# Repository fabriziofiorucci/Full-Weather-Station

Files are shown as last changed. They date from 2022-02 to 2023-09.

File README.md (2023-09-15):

# Full weather station

## Description

This is a MQTT-enabled, weather station powered by a Wemos D1 minicontroller and built with 3D-printed parts. It supports OTA updates.
The weather station is meant to be pole-mounted.

Used sensors and parts are:

- Wemos D1 minicontroller
- Wind speed: Anemometer with analog voltage output (like https://www.adafruit.com/product/1733)
- Visible light: BH1750FVI Light intensity (lux) sensor
- UV light: VEML6070 uv sensor
- Air quality/pollution: Digital Particle Concentration Laser Sensor PMS5003
- Rain quantity: Tipping bucket rain gauge (like https://www.bc-robotics.com/shop/tipping-rain-gauge/)
- Rain level: Capacitive soil moisture sensor
- Temperature and humidity: SHT21
- Pressure: BME280
- Wind speed decoding: ADS1115 16-Bit ADC - 4 Channel with Programmable Gain Amplifier
- LM7805 linear voltage regulator
- 1x 1.8kohm resistor
- 1x 1kohm resistor
- 2, 3, 4 & 5 pins JST XH connectors
- 3 poles PCB screw terminal blocks
- 12-15V 2A power supply
- M3 and M4 Torx screws and bolts
- Cable glands
- 2.54mm / 1 inch PVC pipe

This project is on Thingiverse at https://www.thingiverse.com/thing:5027011

## Schematics

The circuit can be quickly built on a single layer perfboard. It can be powered by a 12V 2A power supply. The onboard LM7805 generates the 5V voltage required for most components. The BME280 sensor is powered at 3.3v directly from the Wemos D1.



## Wemos D1 sketch 

The Wemos sketch can be uploaded using Arduino IDE. The software periodically polls sensors and publishes all readings through MQTT. To reduce wear and extend service life, PMS5003 laser is switched off when not reading.
Over-The-Air updates are supported with no need to physically access the Wemos unit.

The sketch must be configured to point to your MQTT broker and to connect to your WiFi network (see "CUSTOMIZE HERE" sessions)

It relies on https://github.com/SwapBap/PMS for PMS5003 communication

## 3D components

All parts should be printed using:

- weatherproof filament (ASA or PETG)
- 3 walls
- 0.1mm layer height
- print plate adhesion raft in case it's needed

The Stevenson shield is https://www.thingiverse.com/thing:1053967 printed at 65% of the original size:

- Stevenson_screen_Side_Ring.STL (print 5 times)
- Stevenson_screen_Top_Slant_Roof.STL (print once)
- Stevenson_screen_Base.STL (print once)
- 100mmX190mm_Internal_Bracket_for_6_Side_Rings.STL (print once)

The Anemometer 1/4-20 adapter is Anemometer_Adapter_riser_version.stl, from https://www.thingiverse.com/thing:2710360

## Complete build

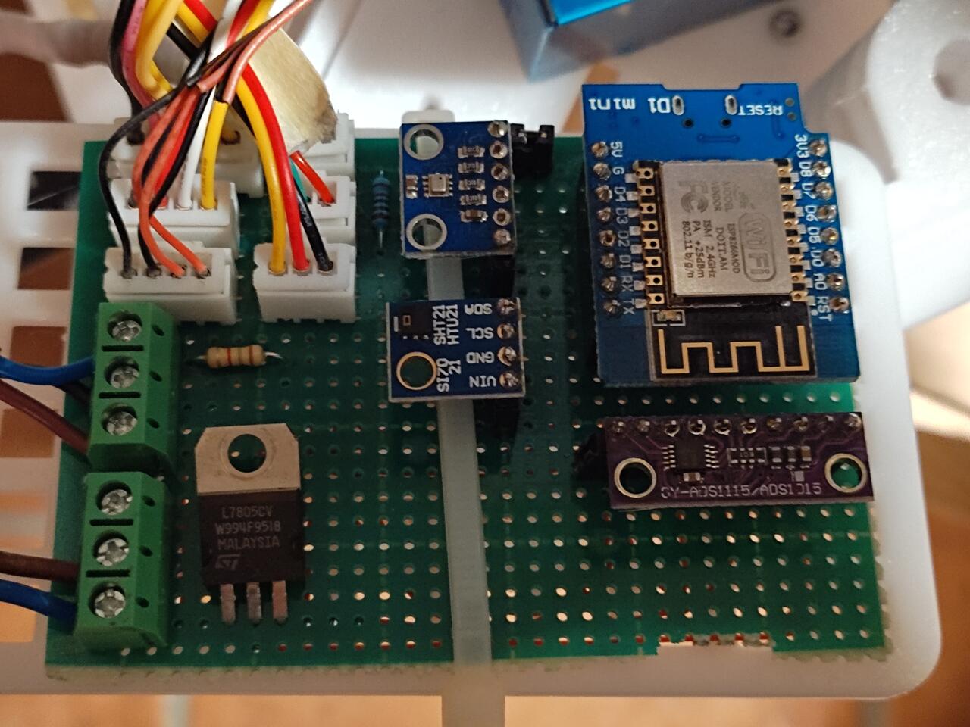
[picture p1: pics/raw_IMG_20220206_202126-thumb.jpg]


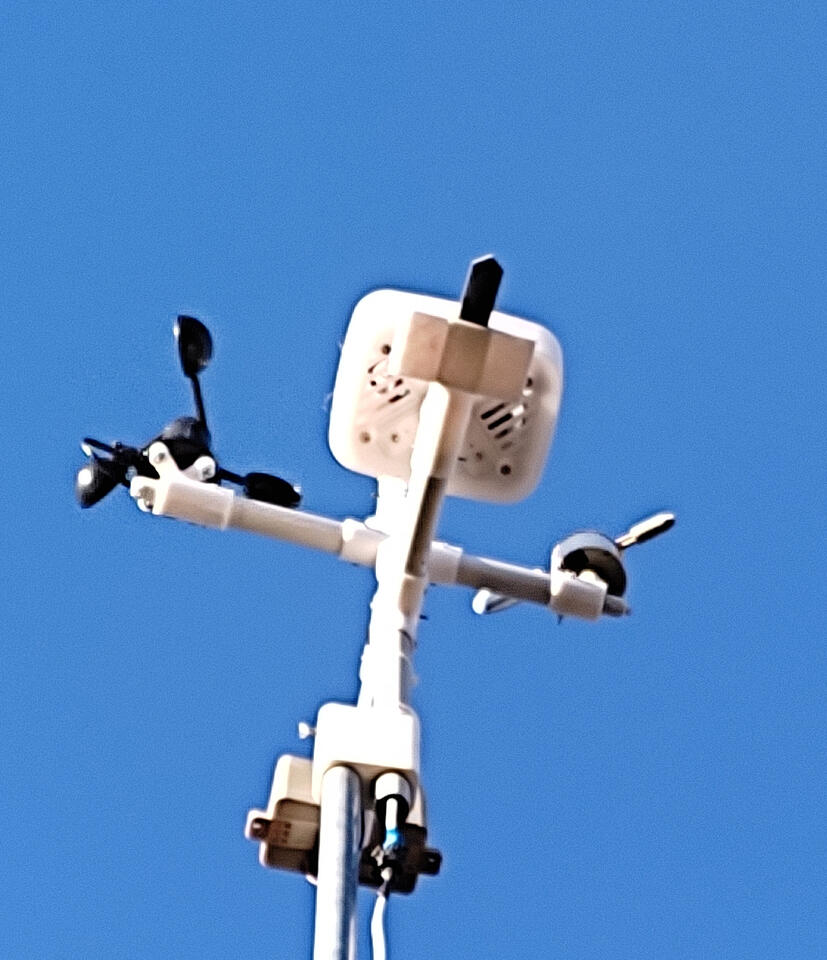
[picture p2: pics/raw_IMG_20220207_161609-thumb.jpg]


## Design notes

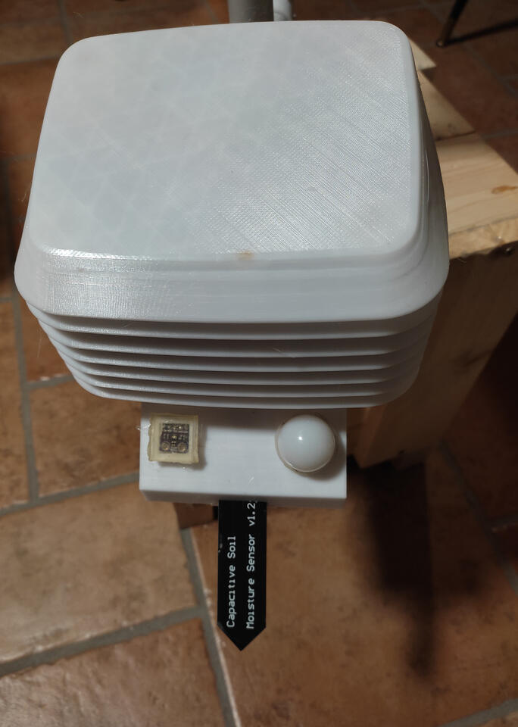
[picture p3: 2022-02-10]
pics/raw_IMG_20220206_173706-thumb.jpg

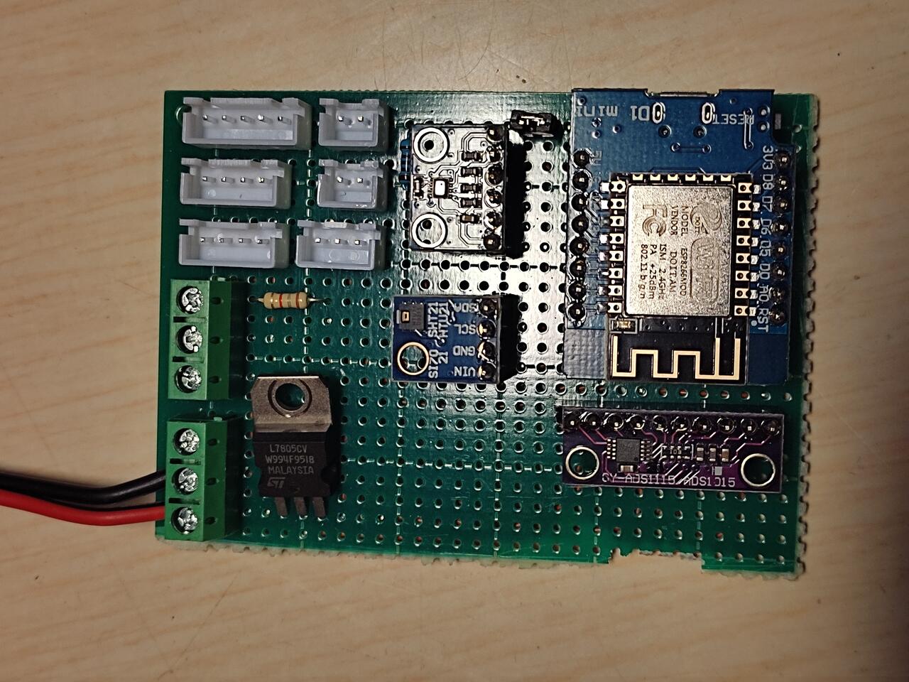
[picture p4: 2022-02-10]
pics/raw_IMG_20220206_202206-thumb.jpg

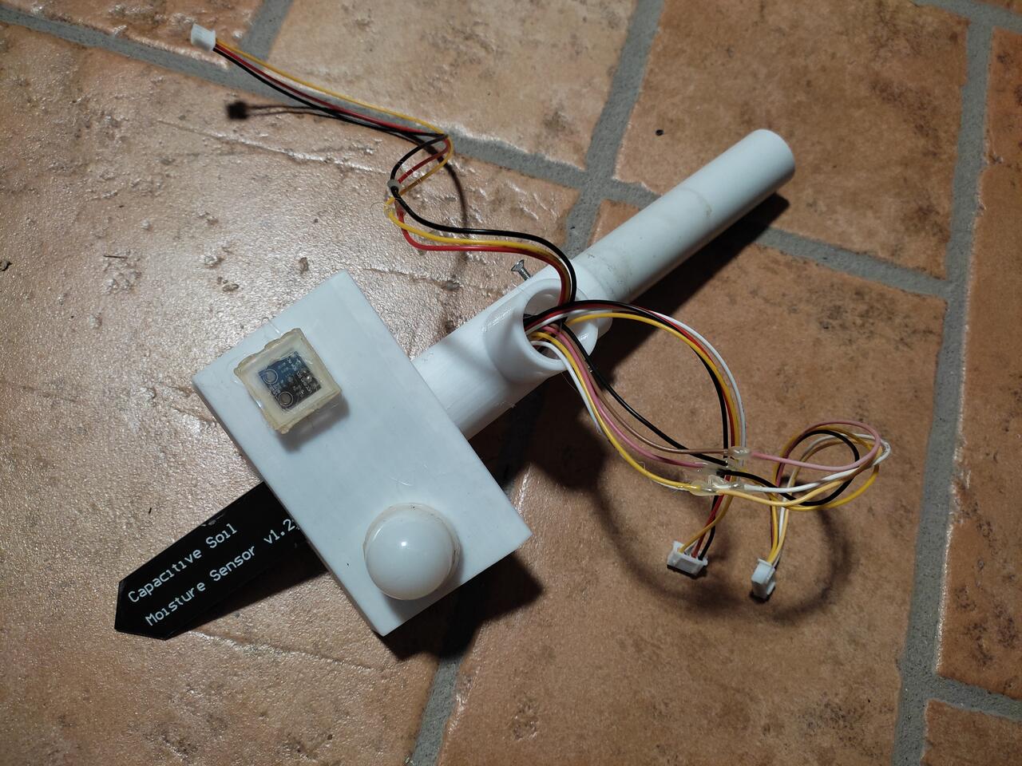
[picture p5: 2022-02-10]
pics/raw_IMG_20220206_144430-thumb.jpg

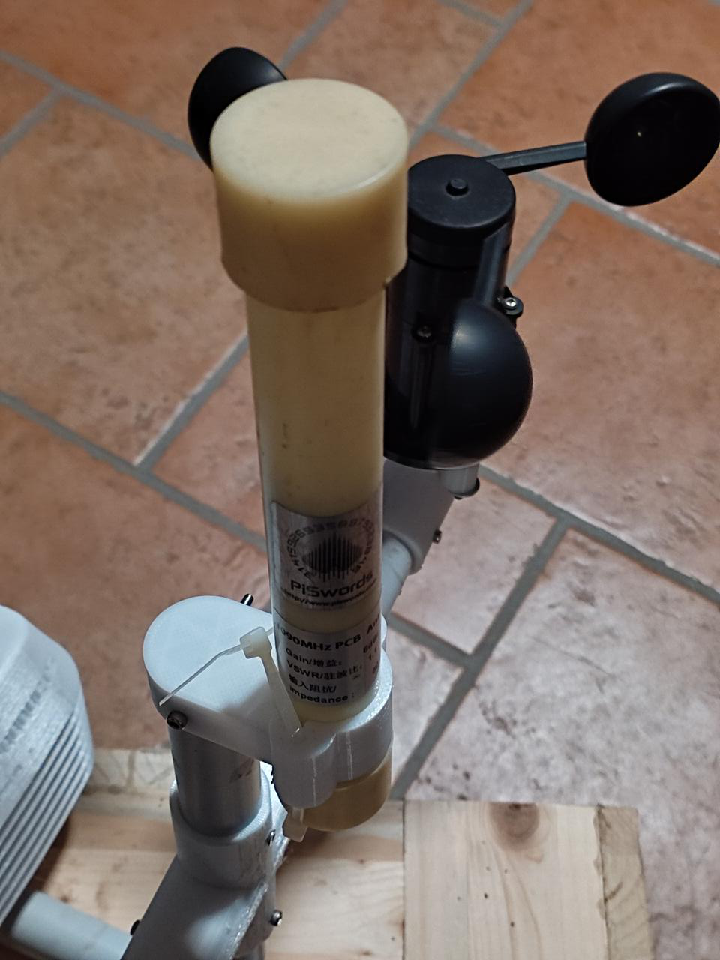
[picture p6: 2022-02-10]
pics/raw_IMG_20220206_173800-thumb.jpg

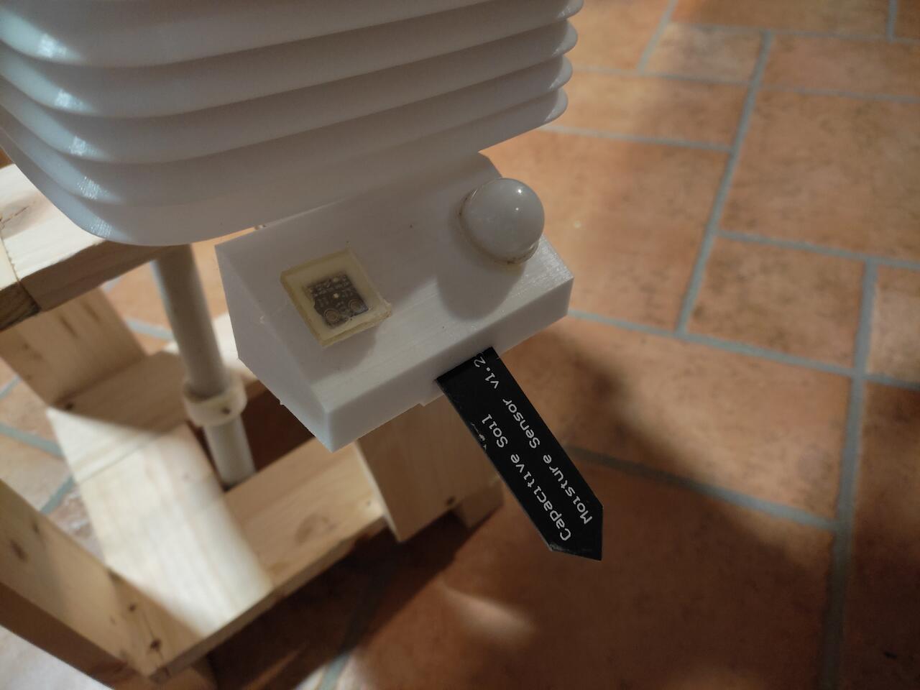
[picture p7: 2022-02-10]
pics/raw_IMG_20220206_173653-thumb.jpg

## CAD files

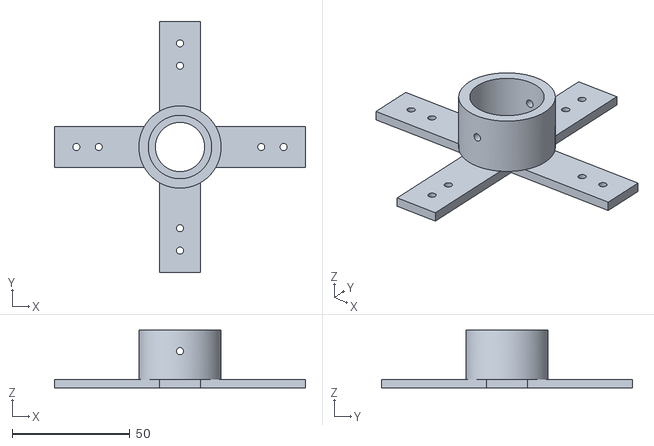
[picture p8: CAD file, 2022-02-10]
CAD/Stevenson base holder 65% scale v4.stl
106.6 x 106.6 x 24.5

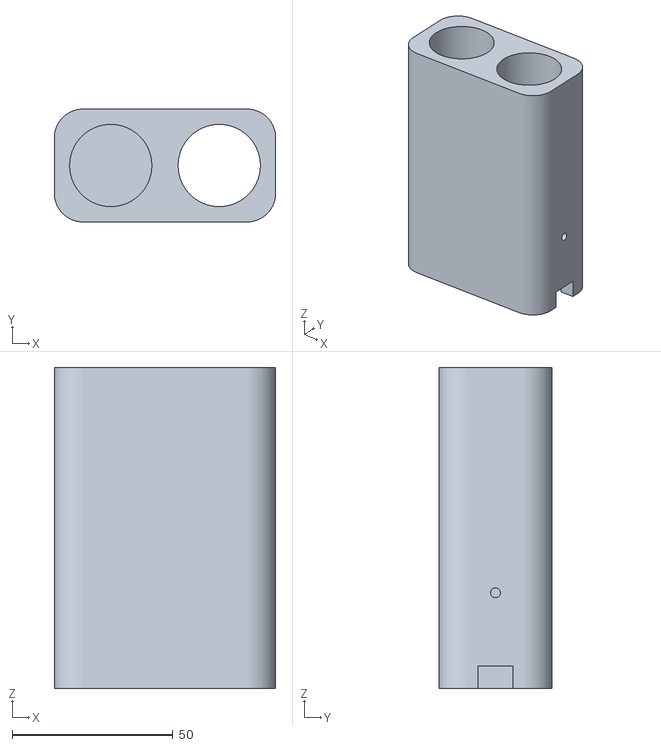
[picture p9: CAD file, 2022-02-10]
CAD/pole clamp.stl
69.0 x 35.2 x 100.0

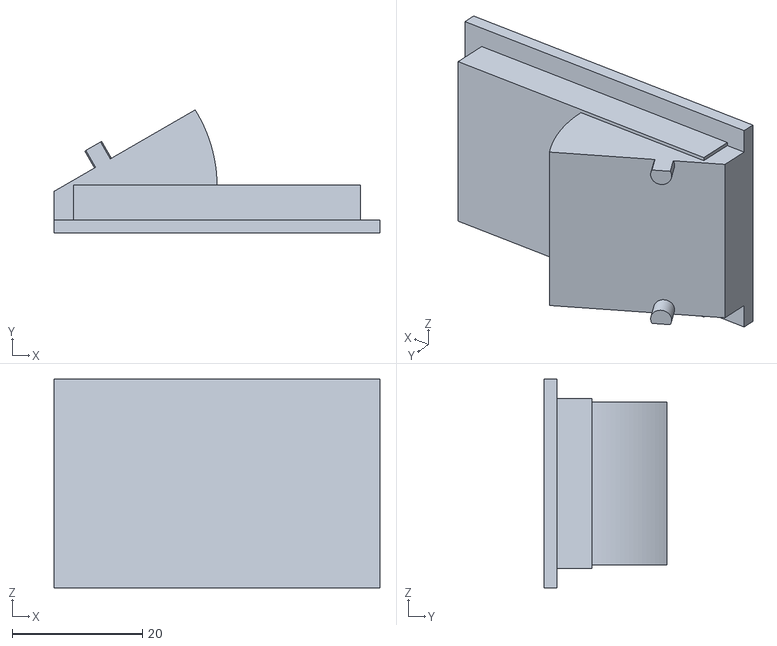
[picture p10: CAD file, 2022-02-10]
CAD/Stevenson to 1 inch pipe L joint v1 - lid.stl
50.0 x 18.9 x 32.0

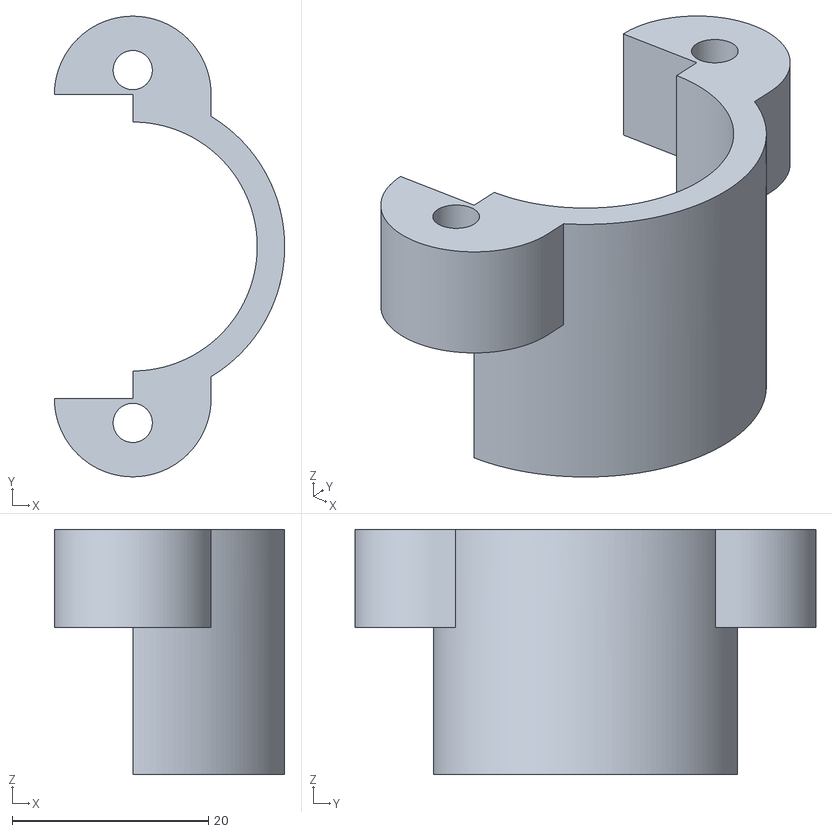
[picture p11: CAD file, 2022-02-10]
CAD/ADS-B latch.stl
23.5 x 47.0 x 25.0

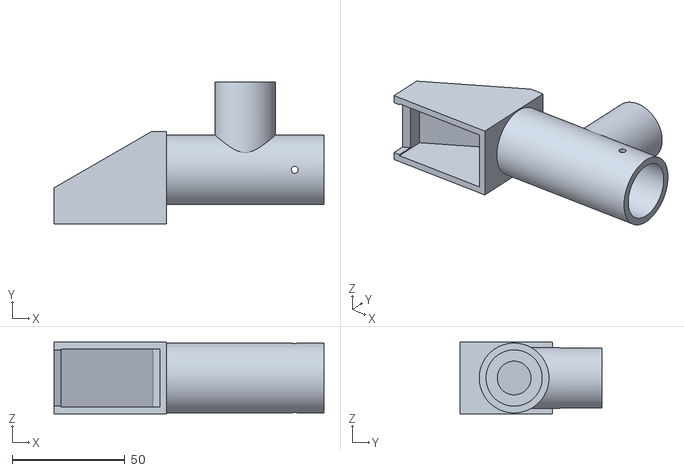
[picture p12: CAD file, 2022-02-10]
CAD/Stevenson to 1 inch pipe L joint v1.stl
120.0 x 63.0 x 32.0

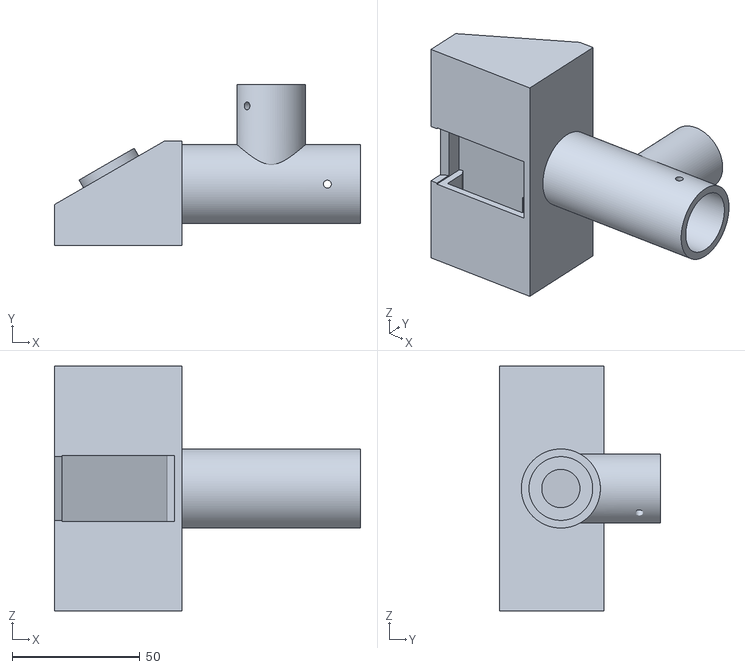
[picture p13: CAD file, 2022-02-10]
CAD/moisture sensor + stevenson to 1 inch pipe.stl
120.0 x 63.0 x 96.0

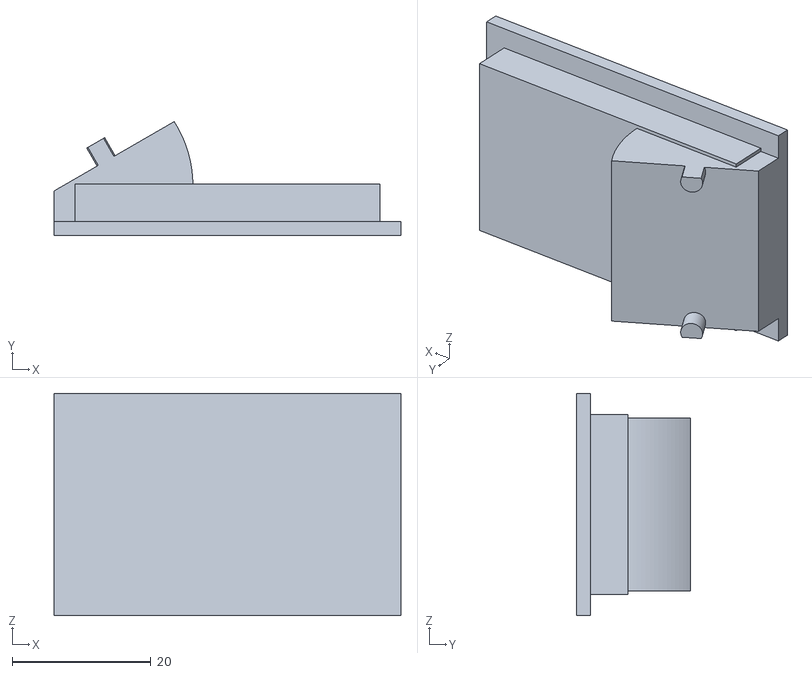
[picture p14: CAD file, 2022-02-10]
CAD/moisture sensor + stevenson to 1 inch pipe - lower lid.stl
50.0 x 16.4 x 32.0

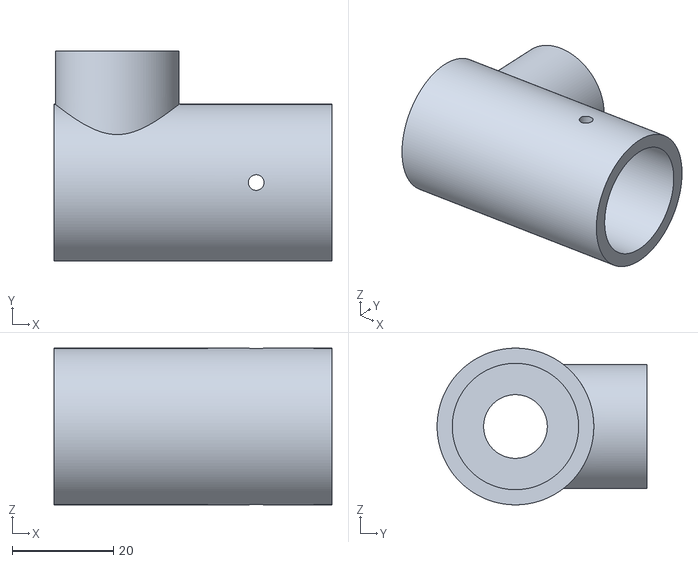
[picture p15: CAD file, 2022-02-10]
CAD/anemometer to 1 inch pipe L joint.stl
55.0 x 41.5 x 31.0

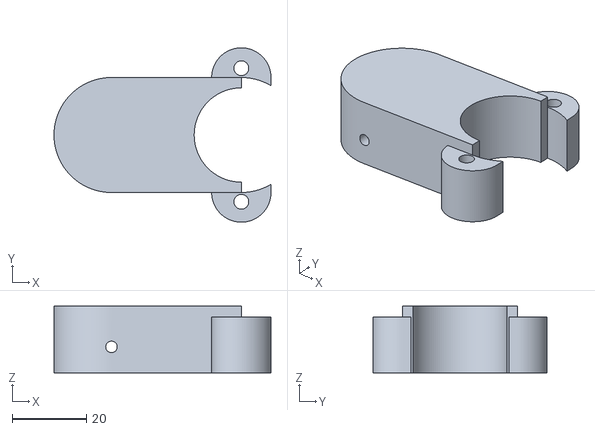
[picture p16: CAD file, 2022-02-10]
CAD/ADS-B to pole.stl
58.5 x 47.0 x 18.0

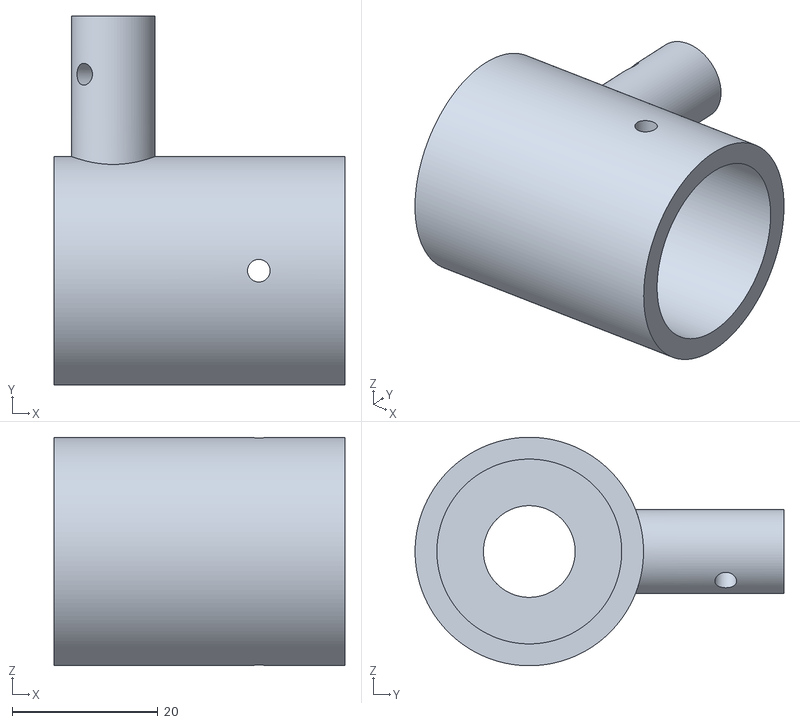
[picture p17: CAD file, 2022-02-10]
CAD/wind vane 1 inch pipe L joint v3.stl
40.0 x 50.7 x 31.4

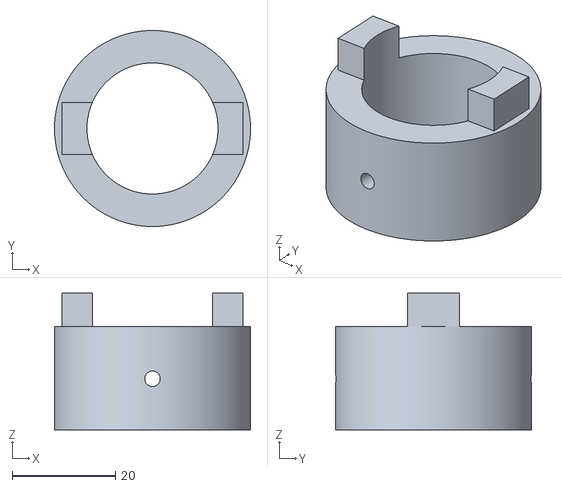
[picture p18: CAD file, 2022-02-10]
CAD/pole holder.stl
38.0 x 38.0 x 26.5

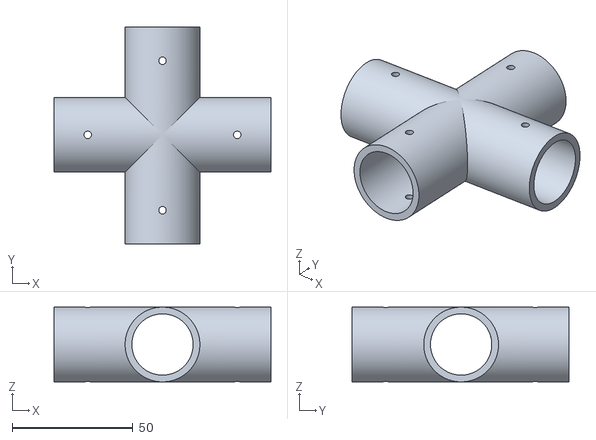
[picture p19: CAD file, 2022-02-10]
CAD/1 inch pipe X joint.stl
90.0 x 90.0 x 31.0

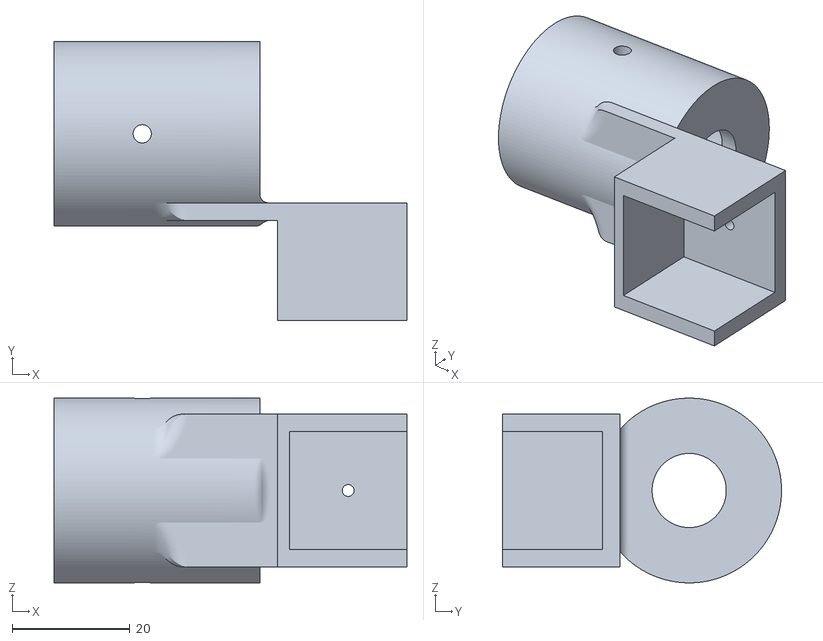
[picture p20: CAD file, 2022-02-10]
CAD/tipping bucket 1 inch pipe joint.stl
60.0 x 47.4 x 31.4

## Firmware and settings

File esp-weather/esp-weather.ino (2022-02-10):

/*
 * Full weather station
 *
 * Wemos D1:
 *
 * A0 -> capacitive soil moisture sensor v1.2
 * D2 -> I2C SDA
 * D1 -> I2C SCL
 * D3 = Rain tipping bucket (tipping bucket wires connected to D3 and GND, D3 set as INPUT_PULLUP)
 * D6 -> to PMS5003 RX (pin 4)
 * D7 -> to PMS5003 TX (pin 5)
 *
 * PMS5003:
 * Pin 1 -> +5vcc
 * Pin 2 -> GND 
 * Pin 3 -> Set @3.3v (low=sleep) - not connected
 * Pin 4 -> RX -> to Wemos D7
 * Pin 5 -> TX -> to Wemos D6
 * Pin 6 -> Reset @3.3v (low=reset) - not connected
 * Pin 7 -> NC
 * Pin 8 -> NC
 *
 * I2C:
 * - BH1750FVI (I2C 0x23 - addr pin to GND)
 * - VEML6070 (I2C 0x38/low address + 0x39/high address)
 * - SHT21 (I2C 0x40)
 * - BMP280 (I2C 0x76)
 * - ADS1115 (I2C 0x48)
 * 
 * ADS1115 gain: 2x, input range=+/-2.048v
 * ADS1115 addr pin = GND (0x48)
 * A0 - +5V reference
 * A1 - Free
 * A2 - Wind vane
 * A3 - Anemometer range 0.4-2v, vcc>=9v connected to ADC through R=1.8k, max current A0=5mA - 0.4V (0 m/s wind) up to 2.0V (for 32.4m/s wind speed)
 *
 * Adafruit Anemometer wires:
 * Brown: power
 * Black: ground
 * Blue : signal
 *
 * Libraries used:
 * 
 * https://github.com/RobTillaart/SHT2x
 * https://github.com/adafruit/Adafruit_ADS1X15
 * https://github.com/adafruit/Adafruit_VEML6070
 * https://github.com/adafruit/Adafruit_BMP280_Library
 * https://github.com/claws/BH1750
 * https://github.com/jandrassy/ArduinoOTA
 * https://github.com/SwapBap/PMS
*/

#include <Wire.h>
#include <ESP8266WiFi.h>
#include <PubSubClient.h>
#include <NTPClient.h>
#include <WiFiUdp.h>
#include <SoftwareSerial.h>
#include "PMS.h"
#include "Adafruit_VEML6070.h"
#include <BH1750.h>
#include <Adafruit_Sensor.h>
#include <Adafruit_BMP280.h>
#include <Adafruit_ADS1X15.h>
#include <ArduinoOTA.h>
#include "SHT2x.h"


// --------------- CUSTOMIZE HERE WIFI PARAMETERS
const char* ssid = "MySSID";
const char* password = "MyWifiPassword";

IPAddress ip(192, 168, 1, 35);
IPAddress gateway(192, 168, 1, 5);
IPAddress subnet(255, 255, 255, 0);


// --------------- CUSTOMIZE HERE MQTT PARAMETERS
const char* mqttServer = "mqtt-server-ip";
const int mqttServerPort = 1883;
const char* mqttClientUsername="esp-weather";
const char* mqttClientPassword="mymqttpassword";

const char* topicRain="esp-weather/rain/percentage";
const char* topicRainTipping="esp-weather/rain/tipping";
const char* topicLightUVraw="esp-weather/light/uv/raw";
const char* topicLightUVlevel="esp-weather/light/uv/level";
const char* topicLightLux="esp-weather/light/lux";
const char* topicBMEtemperature="esp-weather/sht21/temperature";
const char* topicBMEpressure="esp-weather/bme280/pressure";
const char* topicBMEhumidity="esp-weather/sht21/humidity";
const char* topicWindSpeed="esp-weather/wind/speed";
const char* topicWindVane="esp-weather/wind/direction";
const char* debugTopic="esp-weather/debug";
const char* topicADC_a0="esp-weather/ads1115/a0";
const char* topicADC_a1="esp-weather/ads1115/a1";
const char* topicADC_a2="esp-weather/ads1115/a2";
const char* topicADC_a3="esp-weather/ads1115/a3";
const char* controlTopic="esp-weather/control";

// Particulate matter sensor
#define   PMS_STATE_ASLEEP        0   // Low power mode, laser and fan off
#define   PMS_STATE_WAKING_UP     1   // Laser and fan on, not ready yet
#define   PMS_STATE_READY         2   // Warmed up, ready to give data
uint8_t   g_pms_state           = PMS_STATE_WAKING_UP;
uint32_t  g_pms_state_start     = 0;  // Timestamp when PMS state last changed
uint8_t   g_pms_ae_readings_taken  = false;  // true/false: whether any readings have been taken
uint8_t   g_pms_ppd_readings_taken = false;  // true/false: whether PPD readings have been taken

uint16_t  g_pm1p0_sp_value      = 0;  // Standard Particle calibration pm1.0 reading
uint16_t  g_pm2p5_sp_value      = 0;  // Standard Particle calibration pm2.5 reading
uint16_t  g_pm10p0_sp_value     = 0;  // Standard Particle calibration pm10.0 reading

uint16_t  g_pm1p0_ae_value      = 0;  // Atmospheric Environment pm1.0 reading
uint16_t  g_pm2p5_ae_value      = 0;  // Atmospheric Environment pm2.5 reading
uint16_t  g_pm10p0_ae_value     = 0;  // Atmospheric Environment pm10.0 reading

uint32_t  g_pm0p3_ppd_value     = 0;  // Particles Per Deciliter pm0.3 reading
uint32_t  g_pm0p5_ppd_value     = 0;  // Particles Per Deciliter pm0.5 reading
uint32_t  g_pm1p0_ppd_value     = 0;  // Particles Per Deciliter pm1.0 reading
uint32_t  g_pm2p5_ppd_value     = 0;  // Particles Per Deciliter pm2.5 readingpm25
uint32_t  g_pm5p0_ppd_value     = 0;  // Particles Per Deciliter pm5.0 reading
uint32_t  g_pm10p0_ppd_value    = 0;  // Particles Per Deciliter pm10.0 reading

uint32_t    g_pms_warmup_period   =  30;             // Seconds to warm up PMS before reading
uint32_t    g_pms_report_period   = 120;             // Seconds between reports

const char* topicPMS5003aepm1p0="esp-weather/pms5003/ae/pm1p0";
const char* topicPMS5003aepm2p5="esp-weather/pms5003/ae/pm2p5";
const char* topicPMS5003aepm10p0="esp-weather/pms5003/ae/pm10p0";
const char* topicPMS5003ppd0p3="esp-weather/pms5003/ppd/0p3";
const char* topicPMS5003ppd0p5="esp-weather/pms5003/ppd/0p5";
const char* topicPMS5003ppd1p0="esp-weather/pms5003/ppd/1p0";
const char* topicPMS5003ppd2p5="esp-weather/pms5003/ppd/2p5";
const char* topicPMS5003ppd5p0="esp-weather/pms5003/ppd/5p0";
const char* topicPMS5003ppd10p0="esp-weather/pms5003/ppd/10p0";

// PMS5003
SoftwareSerial pmsSerial(D6, D7); // RX pin, TX pin
PMS pms(pmsSerial);                      // Use the software serial port for the PMS
PMS::DATA g_data;

// VEML6070
Adafruit_VEML6070 veml6070 = Adafruit_VEML6070();

// BH1750
BH1750 lightMeter(0x23);

// BMP280
#define SEALEVELPRESSURE_HPA (1013.25)
Adafruit_BMP280 bmp;

// https://community.blynk.cc/t/ads1115-with-wemos-mini-d1/12215
Adafruit_ADS1115 ads;
float Voltage0 = 0.0;
float Voltage1 = 0.0;
float Voltage2 = 0.0;
float Voltage3 = 0.0;
int16_t adc0, adc1, adc2, adc3;

// SHT21
SHT2x sht;

char s[256];

WiFiUDP ntpUDP;
NTPClient timeClient(ntpUDP, "it.pool.ntp.org", 3600, 60000);

WiFiClient wifiClient;
PubSubClient mqttClient(wifiClient);

// Tipping bucket rain sensor
int TIPPING_BUCKET_PIN=D3;
long tippingBucketPulseCount=0;
unsigned long msIRQdebouncingTime = 1;
volatile unsigned long lastIRQmicros;

// Polling interval
long lastMsg = 0;
long pollInterval=5000;


void setup_wifi() {
  delay(10);

  pinMode(LED_BUILTIN, OUTPUT);

  Serial.println();
  Serial.print("Connecting to ");
  Serial.println(ssid);

  WiFi.mode(WIFI_STA);
  WiFi.config(ip, gateway, subnet);
  WiFi.begin(ssid, password);

  //while (WiFi.status() != WL_CONNECTED) {
  for (int i = 0; i < 500 && WiFi.status() != WL_CONNECTED; i++) {
    digitalWrite(LED_BUILTIN, LOW);
    delay(25);
    digitalWrite(LED_BUILTIN, HIGH);
    delay(25);
    Serial.print(".");
  }

  if (WiFi.status() != WL_CONNECTED) {
    Serial.print("Restarting ESP due to loss of Wi-Fi");
    ESP.restart();
  }

  randomSeed(micros());

  Serial.printf("\nWiFi connected to %s\n",ssid);
  Serial.printf("IP address: ");
  Serial.println(WiFi.localIP());
}

void reconnectMqtt() {
  while (!mqttClient.connected()) {
    Serial.print("Attempting MQTT connection...");
    
    if (mqttClient.connect((char *) String(ESP.getChipId()).c_str(),mqttClientUsername,mqttClientPassword)) {
      Serial.println("connected to MQTT");
      mqttClient.publish(debugTopic, "connected to MQTT");
      mqttClient.subscribe(controlTopic);
    } else {
      Serial.print("failed, rc=");
      Serial.print(mqttClient.state());
      Serial.println(" try again in 3 seconds");
      delay(3000);
    }
  }
}

void callback(char* topic, byte* payload, unsigned int length) {
  Serial.print("Got MQTT [");
  Serial.print(topic);
  Serial.print("] = [");
  for (int i = 0; i < length; i++) {
    Serial.print((char)payload[i]);
  }
  Serial.println("]");

  if (strcmp(topic,controlTopic)==0) {
    if ((char)payload[0]=='R') {
      Serial.println("Received MQTT reset, restarting ESP");
      ESP.restart();
    }
  }
}

void ICACHE_RAM_ATTR onTippingBucketPulse()
{
  if((long)(micros() - lastIRQmicros) >= msIRQdebouncingTime * 1000) {
    tippingBucketPulseCount++;
    lastIRQmicros = micros();
  } 
}

void setup() {
  Serial.begin(115200, SERIAL_8N1);

  Serial.println("-----------------------------------------");
  Serial.printf("Chip ID     : %08X\n", ESP.getChipId());
  Serial.printf("Core version: %s\n", ESP.getCoreVersion().c_str());
  Serial.printf("SDK version : %s\n", ESP.getSdkVersion());
  Serial.printf("CPU speed   : %dMhz\n", ESP.getCpuFreqMHz());
  Serial.println("-----------------------------------------");

  pinMode(BUILTIN_LED, OUTPUT);     // Initialize the BUILTIN_LED pin as an output

  setup_wifi();
  mqttClient.setServer(mqttServer, mqttServerPort);
  mqttClient.setCallback(callback);

  unsigned bmp280status;
    bmp280status = bmp.begin(0x76);  

    if (!bmp280status) {
      mqttClient.publish(debugTopic,"BMP280 init error");
    
      Serial.println("Could not find a valid BMP280 sensor, check wiring, address, sensor ID!");
      Serial.print("SensorID was: 0x"); Serial.println(bmp.sensorID(),16);
      Serial.print("        ID of 0xFF probably means a bad address, a BMP 180 or BMP 085\n");
      Serial.print("   ID of 0x56-0x58 represents a BMP 280,\n");
      Serial.print("        ID of 0x60 represents a BME 280.\n");
      Serial.print("        ID of 0x61 represents a BME 680.\n");
    }

  // VEML6070
  veml6070.begin(VEML6070_1_T);

 /*

    BH1750 has six different measurement modes. They are divided in two groups;
    continuous and one-time measurements. In continuous mode, sensor continuously
    measures lightness value. In one-time mode the sensor makes only one
    measurement and then goes into Power Down mode.

    Each mode, has three different precisions:

      - Low Resolution Mode - (4 lx precision, 16ms measurement time)
      - High Resolution Mode - (1 lx precision, 120ms measurement time)
      - High Resolution Mode 2 - (0.5 lx precision, 120ms measurement time)

    By default, the library uses Continuous High Resolution Mode, but you can
    set any other mode, by passing it to BH1750.begin() or BH1750.configure()
    functions.

    [!] Remember, if you use One-Time mode, your sensor will go to Power Down
    mode each time, when it completes a measurement and you've read it.

    Full mode list:

      BH1750_CONTINUOUS_LOW_RES_MODE
      BH1750_CONTINUOUS_HIGH_RES_MODE (default)
      BH1750_CONTINUOUS_HIGH_RES_MODE_2

      BH1750_ONE_TIME_LOW_RES_MODE
      BH1750_ONE_TIME_HIGH_RES_MODE
      BH1750_ONE_TIME_HIGH_RES_MODE_2

  */
  if (!lightMeter.begin(BH1750::CONTINUOUS_HIGH_RES_MODE)) {
    Serial.println("Error initialising BH1750");
    mqttClient.publish(debugTopic,"BH1750 init error");
  }

  // The ADC input range (or gain) can be changed via the following
  // functions, but be careful never to exceed VDD +0.3V max, or to
  // exceed the upper and lower limits if you adjust the input range!
  // Setting these values incorrectly may destroy your ADC!
  //                                                                ADS1015  ADS1115
  //                                                                -------  -------
  // ads.setGain(GAIN_TWOTHIRDS);  // 2/3x gain +/- 6.144V  1 bit = 3mV      0.1875mV (default)
  // ads.setGain(GAIN_ONE);           // 1x gain   +/- 4.096V  1 bit = 2mV      0.125mV
  ads.setGain(GAIN_TWO);        // 2x gain   +/- 2.048V  1 bit = 1mV      0.0625mV
  // ads.setGain(GAIN_FOUR);       // 4x gain   +/- 1.024V  1 bit = 0.5mV    0.03125mV
  // ads.setGain(GAIN_EIGHT);      // 8x gain   +/- 0.512V  1 bit = 0.25mV   0.015625mV
  // ads.setGain(GAIN_SIXTEEN);    // 16x gain  +/- 0.256V  1 bit = 0.125mV  0.0078125mV
  
  ads.begin(0x48);

  // SHT21
  sht.begin();

  // PMS5003
  pmsSerial.begin(9600);   // Connection for PMS5003
  pms.passiveMode();                // Tell PMS to stop sending data automatically
  delay(100);
  Serial.println("PMS5003: wakeup");
  pms.wakeUp();                     // Tell PMS to wake up (turn on fan and laser)

  // Rain tipping bucket
  pinMode(TIPPING_BUCKET_PIN,INPUT_PULLUP);
  attachInterrupt(digitalPinToInterrupt(TIPPING_BUCKET_PIN), onTippingBucketPulse, FALLING);

  ArduinoOTA.setPort(8266);
  ArduinoOTA.setHostname("esp-weather");
  ArduinoOTA.setPassword((const char *)"OTApassword");

  ArduinoOTA.onStart([]() {
    Serial.println("Start");
  });
  ArduinoOTA.onEnd([]() {
    Serial.println("\nEnd");
  });
  ArduinoOTA.onProgress([](unsigned int progress, unsigned int total) {
    Serial.printf("Progress: %u%%\r", (progress / (total / 100)));
  });
  ArduinoOTA.onError([](ota_error_t error) {
    Serial.printf("Error[%u]: ", error);
    if (error == OTA_AUTH_ERROR) Serial.println("Auth Failed");
    else if (error == OTA_BEGIN_ERROR) Serial.println("Begin Failed");
    else if (error == OTA_CONNECT_ERROR) Serial.println("Connect Failed");
    else if (error == OTA_RECEIVE_ERROR) Serial.println("Receive Failed");
    else if (error == OTA_END_ERROR) Serial.println("End Failed");
  });
  ArduinoOTA.begin();

  if (!mqttClient.connected()) {
    reconnectMqtt();
  }

  mqttClient.publish(controlTopic, "starting", false);
}

void pms5003Read()
{
  uint32_t time_now = millis();

  // Check if we've been in the sleep state for long enough
  if (PMS_STATE_ASLEEP == g_pms_state)
  {
    if (time_now - g_pms_state_start
        >= ((g_pms_report_period * 1000) - (g_pms_warmup_period * 1000)))
    {
      // It's time to wake up the sensor
      Serial.println("PMS5003: wakeup");
      pms.wakeUp();
      g_pms_state_start = time_now;
      g_pms_state = PMS_STATE_WAKING_UP;
    }
  }

  // Check if we've been in the waking up state for long enough
  if (PMS_STATE_WAKING_UP == g_pms_state)
  {
    //Serial.println("Checking if wakeup state is long enough");
    if (time_now - g_pms_state_start
        >= (g_pms_warmup_period * 1000))
    {
      g_pms_state_start = time_now;
      g_pms_state = PMS_STATE_READY;
    }
  }

  // Put the most recent values into globals for reference elsewhere
  if (PMS_STATE_READY == g_pms_state)
  {
    pms.requestRead();
    Serial.println("PMS5003: ready");
    if (pms.readUntil(g_data))  // Use a blocking road to make sure we get values
    {
      g_pm1p0_sp_value   = g_data.PM_SP_UG_1_0;
      g_pm2p5_sp_value   = g_data.PM_SP_UG_2_5;
      g_pm10p0_sp_value  = g_data.PM_SP_UG_10_0;

      g_pm1p0_ae_value   = g_data.PM_AE_UG_1_0;
      g_pm2p5_ae_value   = g_data.PM_AE_UG_2_5;
      g_pm10p0_ae_value  = g_data.PM_AE_UG_10_0;

      sprintf(s,"PMS5003: sp+ae [%u %u %u %u %u %u]",g_pm1p0_sp_value,g_pm2p5_sp_value,g_pm10p0_sp_value,g_pm1p0_ae_value,g_pm2p5_ae_value,g_pm10p0_ae_value);
      Serial.println(s);

      g_pms_ae_readings_taken = true;

      // This condition below should NOT be required, but currently I get all
      // 0 values for the PPD results every second time. This check only updates
      // the global values if there is a non-zero result for any of the values:
      if (g_data.PM_TOTALPARTICLES_0_3 + g_data.PM_TOTALPARTICLES_0_5
          + g_data.PM_TOTALPARTICLES_1_0 + g_data.PM_TOTALPARTICLES_2_5
          + g_data.PM_TOTALPARTICLES_5_0 + g_data.PM_TOTALPARTICLES_10_0
          != 0)
      {
        g_pm0p3_ppd_value  = g_data.PM_TOTALPARTICLES_0_3;
        g_pm0p5_ppd_value  = g_data.PM_TOTALPARTICLES_0_5;
        g_pm1p0_ppd_value  = g_data.PM_TOTALPARTICLES_1_0;
        g_pm2p5_ppd_value  = g_data.PM_TOTALPARTICLES_2_5;
        g_pm5p0_ppd_value  = g_data.PM_TOTALPARTICLES_5_0;
        g_pm10p0_ppd_value = g_data.PM_TOTALPARTICLES_10_0;
        g_pms_ppd_readings_taken = true;

        sprintf(s,"PMS5003: ppd [%u %u %u %u %u %u]",g_pm0p3_ppd_value,g_pm0p5_ppd_value,g_pm1p0_ppd_value,g_pm2p5_ppd_value,g_pm5p0_ppd_value,g_pm10p0_ppd_value);
        Serial.println(s);
      } else {
        Serial.println("PMS5003: ppd readings 0");
      }

      Serial.println("PMS5003: sleep");
      pms.sleep();

      g_pms_state_start = time_now;
      g_pms_state = PMS_STATE_ASLEEP;
    }
  }
}

void reportPMS5003ToMqtt()
{
  if (true == g_pms_ae_readings_taken)
  {
    /* Report PM1.0 AE value */
    mqttClient.publish(topicPMS5003aepm1p0, (char *) String(g_pm1p0_ae_value).c_str());

    /* Report PM2.5 AE value */
    mqttClient.publish(topicPMS5003aepm2p5, (char *) String(g_pm2p5_ae_value).c_str());

    /* Report PM10.0 AE value */
    mqttClient.publish(topicPMS5003aepm10p0, (char *) String(g_pm10p0_ae_value).c_str());

    g_pms_ae_readings_taken=false;
  }

  if (true == g_pms_ppd_readings_taken)
  {
    /* Report PM0.3 PPD value */
    mqttClient.publish(topicPMS5003ppd0p3,(char *) String(g_pm0p3_ppd_value).c_str());

    /* Report PM0.5 PPD value */
    mqttClient.publish(topicPMS5003ppd0p5,(char *) String(g_pm0p5_ppd_value).c_str());

    /* Report PM1.0 PPD value */
    mqttClient.publish(topicPMS5003ppd1p0,(char *) String(g_pm1p0_ppd_value).c_str());

    /* Report PM2.5 PPD value */
    mqttClient.publish(topicPMS5003ppd2p5,(char *) String(g_pm2p5_ppd_value).c_str());

    /* Report PM5.0 PPD value */
    mqttClient.publish(topicPMS5003ppd5p0,(char *) String(g_pm5p0_ppd_value).c_str());

    /* Report PM10.0 PPD value */
    mqttClient.publish(topicPMS5003ppd10p0,(char *) String(g_pm10p0_ppd_value).c_str());
    
    g_pms_ppd_readings_taken=false;
  }
}
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
void loop()
{
  ArduinoOTA.handle();

  if (!mqttClient.connected()) {
    reconnectMqtt();
  }

  mqttClient.loop();
  
  pms5003Read();
  
  long now = millis();
  if (now - lastMsg > pollInterval) {
    lastMsg = now;

    // Capacitive rain sensor
    float rainSensorValue = analogRead(A0);
    Serial.print("Rain: ");
    Serial.println(rainSensorValue);
    mqttClient.publish(topicRain,(char*)String(rainSensorValue).c_str());

    // Rain tipping bucket
    long tippingBucketReading=tippingBucketPulseCount;
    tippingBucketPulseCount=0;
    Serial.print("Rain tipping   :");
    Serial.println(tippingBucketReading);
    mqttClient.publish(topicRainTipping, (char *)String(tippingBucketReading).c_str());

    // VEML6070
    // LEVEL* UV Index (VEML6070 raw reading)
    // =====     ========  =====
    // LOW       0-2        
    // MODERATE  3-5        2241
    // HIGH      6-7        4482
    // VERY HIGH 8-10       5976
    // EXTREME   >=11       8217
    //
    // int(raw reading / 747) = UV index
    int uvSensorValue=veml6070.readUV();
    Serial.print("UV  : ");
    Serial.print(uvSensorValue);
    Serial.print(" - level ");
    Serial.println(uvSensorValue/747);
    mqttClient.publish(topicLightUVraw,(char*)String(uvSensorValue).c_str());
    mqttClient.publish(topicLightUVlevel,(char*)String(uvSensorValue/747).c_str());

    // BH1750
    float lux = lightMeter.readLightLevel();
    sprintf(s,"Lux : %.2flx",lux);
    Serial.println(s);
    mqttClient.publish(topicLightLux,(char*)String(lux).c_str());

    float f;
    
    // BMP280
    
    //f=bmp.readTemperature();
    //sprintf(s,"Temp: %.2fC",f);
    //Serial.println(s);
    //mqttClient.publish(topicBMEtemperature,(char*)String(f).c_str());

    f=bmp.readPressure()/100.0F;
    sprintf(s,"Pres: %.2fhPa",f);
    Serial.println(s);
    mqttClient.publish(topicBMEpressure,(char*)String(f).c_str());

    //f=bme.readHumidity();
    //sprintf(s,"Hum : %.2f%%",f);
    //Serial.println(s);
    //mqttClient.publish(topicBMEhumidity,(char*)String(f).c_str());
    
    // SHT21
    sht.read();
    
    f=sht.getTemperature();
    sprintf(s,"Temp: %.2fC",f);
    Serial.println(s);
    mqttClient.publish(topicBMEtemperature,(char*)String(f).c_str());

    f=sht.getHumidity();
    sprintf(s,"Hum : %.2f%%",f);
    Serial.println(s);
    mqttClient.publish(topicBMEhumidity,(char*)String(f).c_str());

    // ADS1115
    readADS1115();

    //mqttClient.publish(topicADC_a0, (char *) String(adc0).c_str());
    //mqttClient.publish(topicADC_a1, (char *) String(adc1).c_str());
    //mqttClient.publish(topicADC_a2, (char *) String(adc2).c_str());
    //mqttClient.publish(topicADC_a3, (char *) String(adc3).c_str());

   Serial.print("A0 (+5V)       : ");
   Serial.println((float)(Voltage0),2);
  
   Serial.print("A1 (free)      : ");
   Serial.println((float)(Voltage1),2);

   Serial.print("A2 (wind vane) : ");
   Serial.println((float)(Voltage2),2);
  
   Serial.print("A3 (wind speed): ");
   Serial.print((float)(Voltage3),2);
   Serial.print("  Speed: ");
   float windSpeed=(Voltage3-0.394)*32.4/1.6;
   if(windSpeed<0) {
     windSpeed=0;
   }
   Serial.println((float)(windSpeed),2);

   mqttClient.publish(topicWindSpeed, (char *) String(windSpeed).c_str());

   // Wind vane
   int windDirectionDegrees=0;
   if (adc2 >= 1000 and adc2 <= 1999) { windDirectionDegrees = 0; }
   else if (adc2 >= 4000 and adc2 <= 6999) { windDirectionDegrees = 45; }
   else if (adc2 >= 20000 and adc2 <= 39999) { windDirectionDegrees = 90; }
   else if (adc2 >= 10000 and adc2 <= 19999) { windDirectionDegrees = 135; }
   else if (adc2 >= 7000 and adc2 <= 9999) { windDirectionDegrees = 180; }
   else if (adc2 >= 2000 and adc2 <= 3999) { windDirectionDegrees = 225; }
   else if (adc2 >= 300 and adc2 <= 499) { windDirectionDegrees = 270; }
   else if (adc2 >= 500 and adc2 <= 999) { windDirectionDegrees = 315; }
   else { windDirectionDegrees = -90; }

   windDirectionDegrees = windDirectionDegrees - 180;
   if (windDirectionDegrees>359) { windDirectionDegrees = windDirectionDegrees - 359; }
   if (windDirectionDegrees<0) { windDirectionDegrees = 360 + windDirectionDegrees; }

   mqttClient.publish(topicWindVane, (char *) String(windDirectionDegrees).c_str());
  
    // PMS5003
    reportPMS5003ToMqtt();

    Serial.println("----------------");
  }
}
